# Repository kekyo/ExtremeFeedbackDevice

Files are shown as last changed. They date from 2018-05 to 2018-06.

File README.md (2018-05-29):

# Extreme feedback device (XFD) on ESP8266

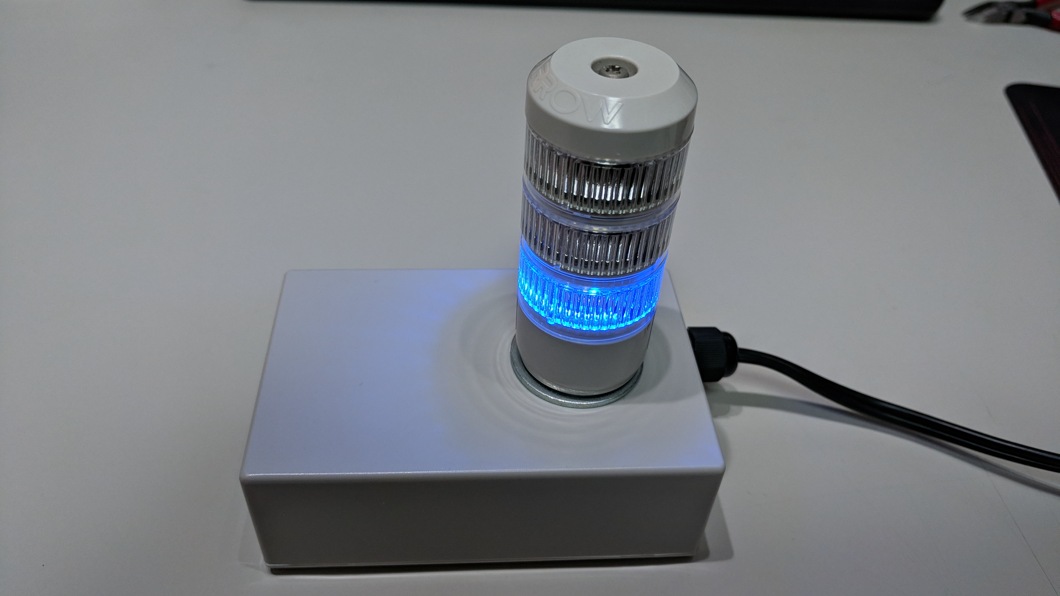
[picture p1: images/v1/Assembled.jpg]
Assembled unit (version 1)


* Still under construction...

## What's this?

* It's extreme feedback device (called XFD useful agile software development) running on ESP8266 (aka ESP-WROOM-02).
* I made custom schematic and artwork.
  * Use EAGLE 8
* I wrote sequencer code by C++ on ESP8266-Arduino IDE. (WIP)

## Features

* We can use signal device with 4 ports.
* For example, port 1, 2, 3 assign signal light's "Green", "Yellow" and "Red" leds. Port 4 assign buzzer.
* Signal device has to have one kind of commonly regulated voltage. I use +24V-0V based signal light.
  * Final output switcher is open-collectored transister using TOSHIBA "TD62064." https://toshiba.semicon-storage.com/info/docget.jsp?did=2229&prodName=TD62064BP1G
  * I use ARROW Electronics "AUSG-24" (In japanese): https://www.proface.co.jp/signaling/product/product_detail.php?unique_id=AUSG

## Schematic and artwork

* I'll order PCB to [Fusion PCB](https://www.seeedstudio.com/fusion_pcb.html).

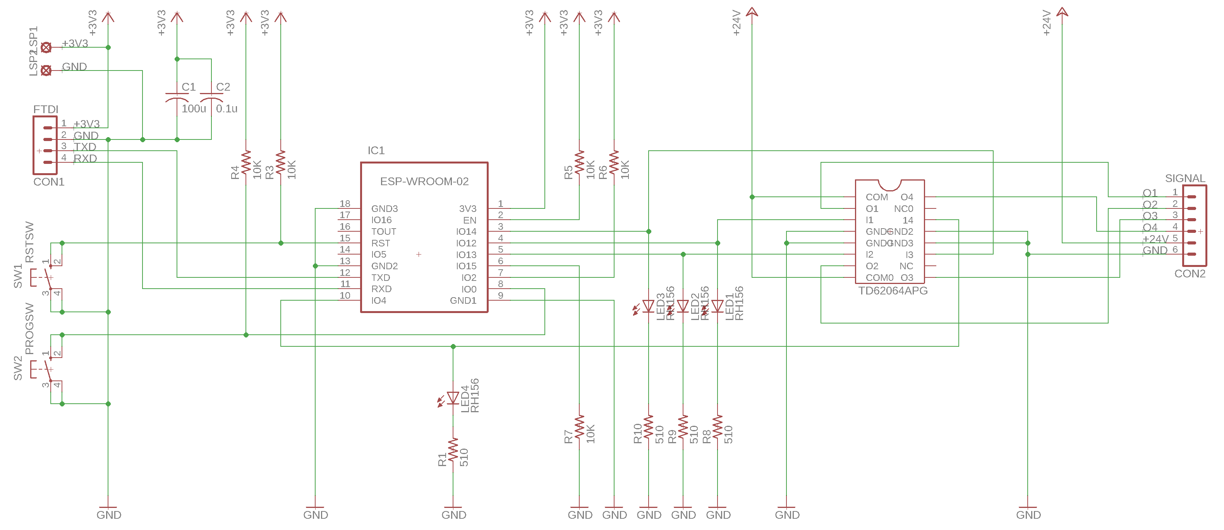
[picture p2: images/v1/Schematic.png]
Schematic


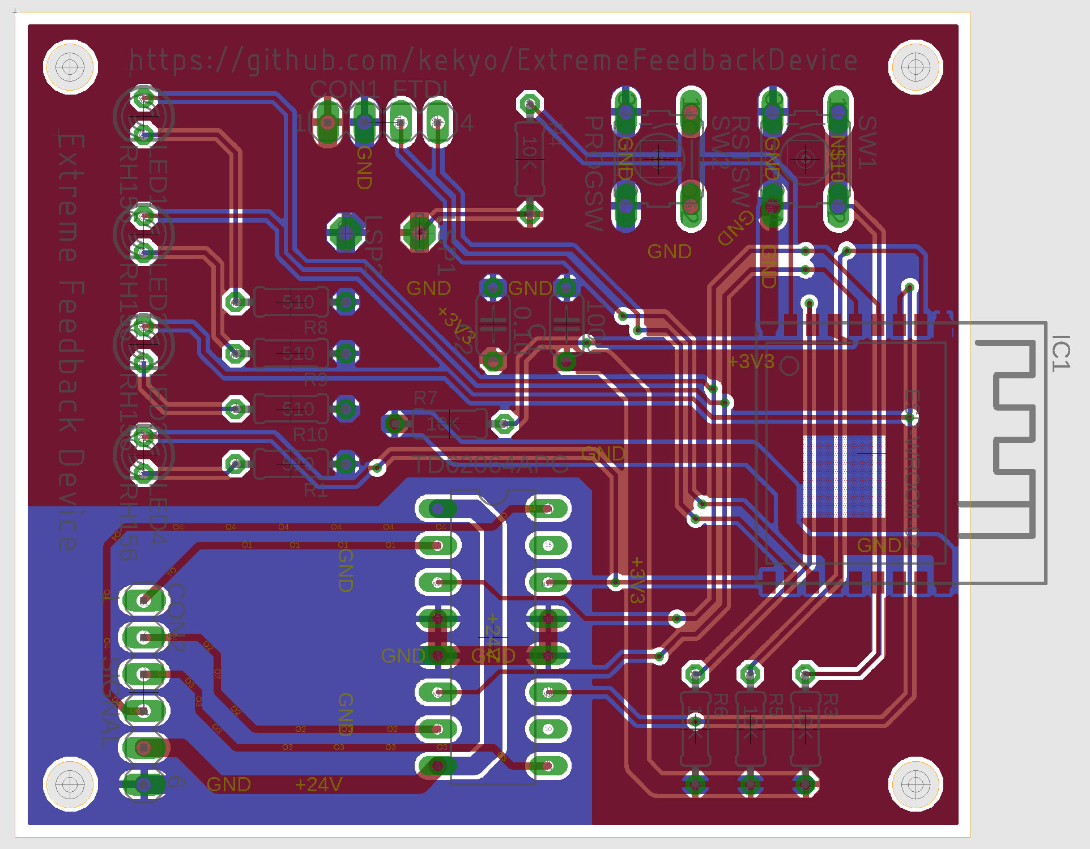
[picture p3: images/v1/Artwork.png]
Artwork


## License

* Under Apache v2

## Background

* At first, I was exciting agile software development weaves. I made XFD device in 2006.
  * It was very standard formal style, using the signal light.
  * I did have no idea how to communicate easy way between PC/Server and devices. So I made with PC's printer parallel port.

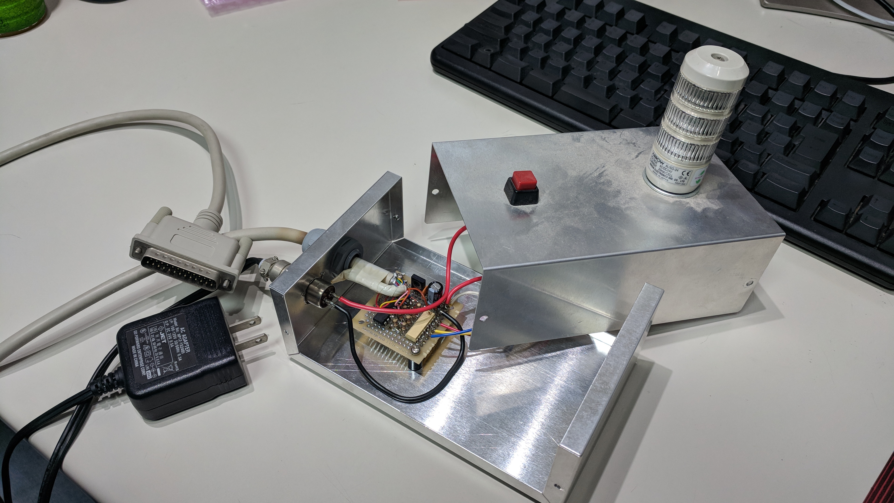
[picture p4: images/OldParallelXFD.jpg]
Old XFD by parallel interface


* Today, we can communicate easier using a lot of procedures, USB/LAN/Wifi/Bluetooth and more. The parallel port obsoleted.
* I'm beginning to redesign for modern-style device communication. The ESP8266 totally better balanced module for IoT platform. I use ESP8266 and redesign XFD for basic boilerplate :)

## History

* first_pcb: Designed output signal with darlington transistor array. It's very simple board, contains only ESP-WROOM-02 and TrA.

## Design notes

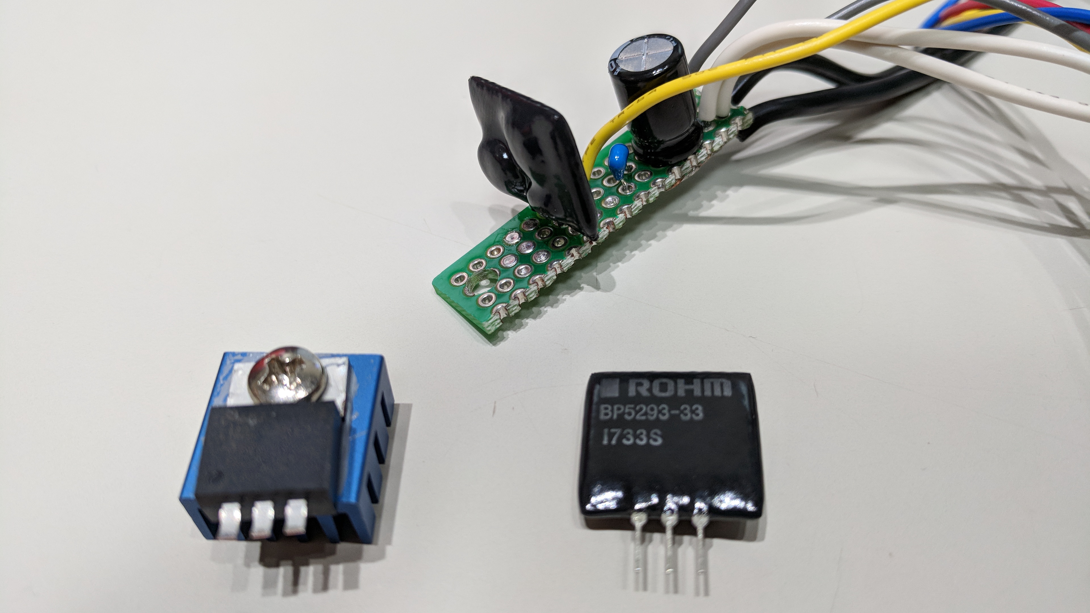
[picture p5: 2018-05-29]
images/v1/SwitchingRegulator.jpg

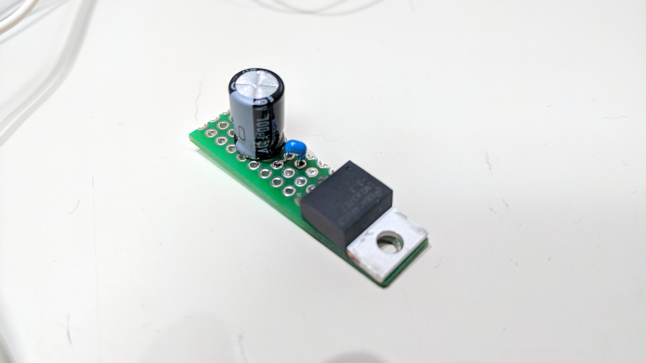
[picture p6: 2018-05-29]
images/v1/PowerBoard.jpg

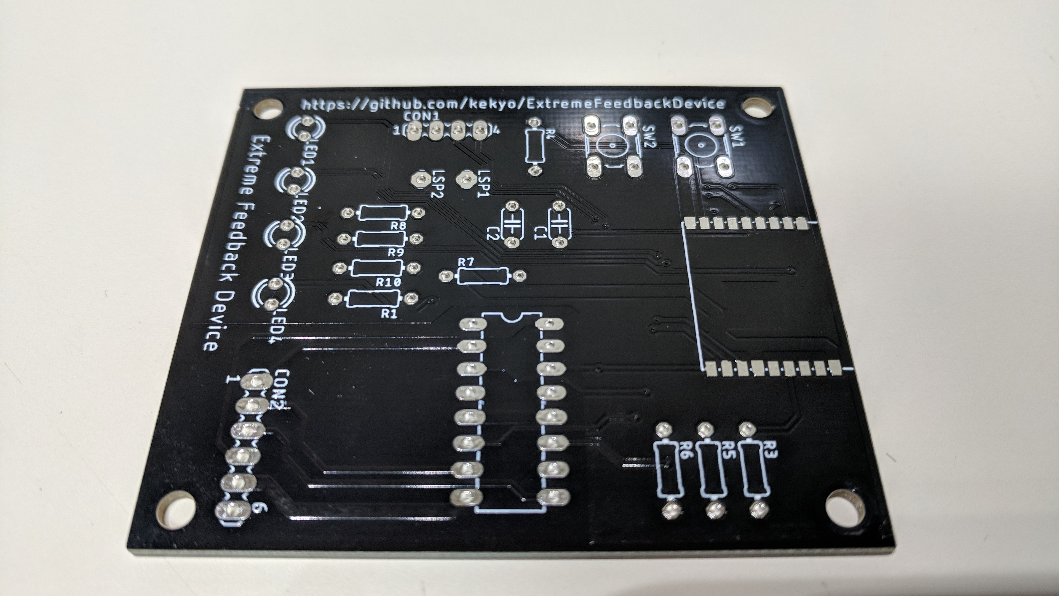
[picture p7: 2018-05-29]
images/v1/Before.jpg

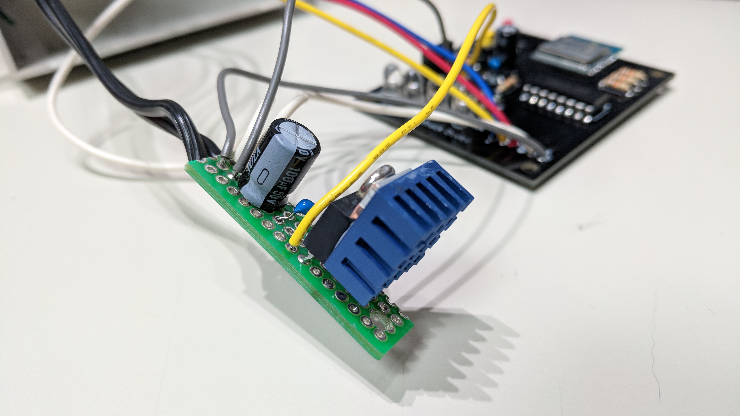
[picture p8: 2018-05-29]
images/v1/TooHotAtRegulator.jpg

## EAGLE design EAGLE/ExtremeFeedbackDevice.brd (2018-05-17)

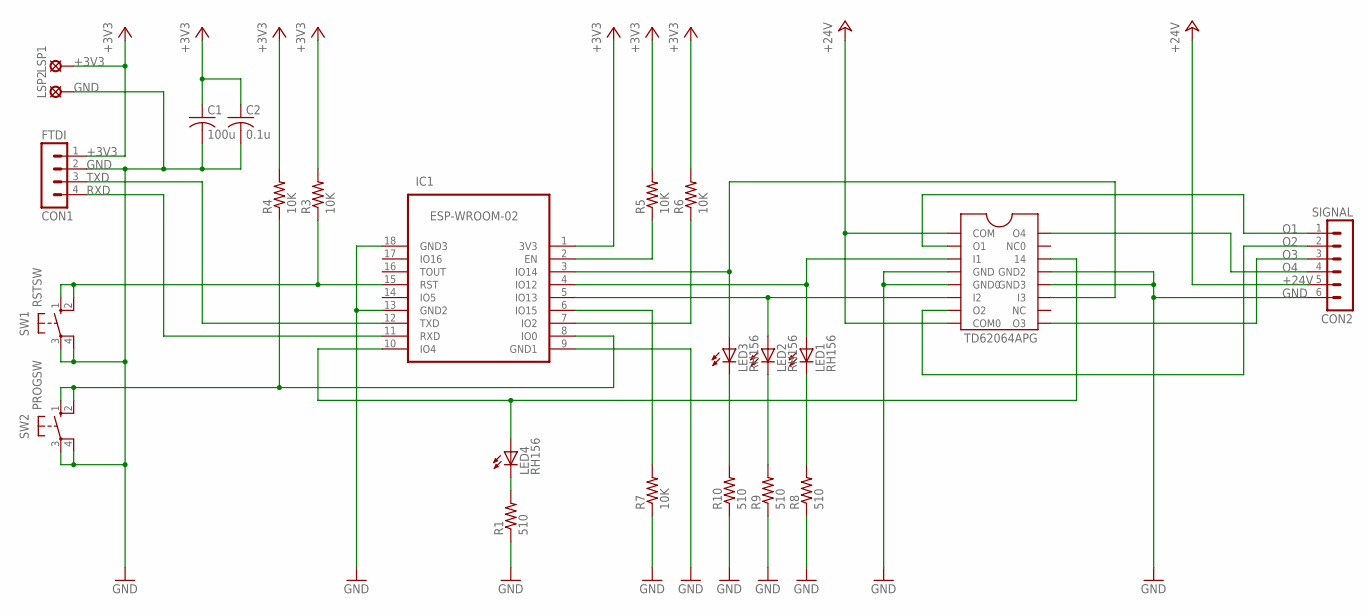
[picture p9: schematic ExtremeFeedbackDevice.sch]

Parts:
C1: 100u; C050-024X044
C2: 0.1u; C050-024X044
CON1: FTDI; MA04-1
CON2: SIGNAL; MA06-1
IC1: ESP-WROOM-02; FRONT-FACE
IC2: IC2; TD62064APG
LED1, LED2, LED3, LED4: RH156; LED3MM
LSP1, LSP2: LSP10
R1, R8, R9, R10: 510; 0204/7
R3, R4, R5, R6, R7: 10K; 0204/7
SW1: RSTSW; B3F-10XX
SW2: PROGSW; B3F-10XX

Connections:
+3V3: C1.1, C2.1, CON1.1, IC1.1 (3V3), LSP1.MP, R3.2, R4.2, R5.2, R6.2
+24V: CON2.5, IC2.1 (COM), IC2.8 (COM0)
GND: C1.2, C2.2, CON1.2, CON2.6, IC1.9 (GND1), IC1.13 (GND2), IC1.18 (GND3), IC2.4 (GND), IC2.5 (GND0), IC2.12 (GND3), IC2.13 (GND2), LSP2.MP, R1.1, R7.1, R8.1, R9.1, R10.1, SW1.3, SW1.4 (P1), SW2.3, SW2.4 (P1)
unnamed: IC1.8 (IO0), R4.1, SW2.1 (S), SW2.2 (S1)
unnamed: IC1.5 (IO13), IC2.6 (I2), LED2.A
unnamed: LED1.K (C), R8.2
unnamed: LED2.K (C), R9.2
unnamed: IC1.3 (IO14), IC2.11 (I3), LED3.A
unnamed: IC1.4 (IO12), IC2.3 (I1), LED1.A
unnamed: IC1.15 (RST), R3.1, SW1.1 (S), SW1.2 (S1)
unnamed: LED3.K (C), R10.2
unnamed: IC1.2 (EN), R5.1
unnamed: IC1.7 (IO2), R6.1
unnamed: IC1.6 (IO15), R7.2
unnamed: IC1.10 (IO4), IC2.14, LED4.A
unnamed: LED4.K (C), R1.2
O1: CON2.1, IC2.2 (O1)
O2: CON2.2, IC2.7 (O2)
O3: CON2.3, IC2.9 (O3)
O4: CON2.4, IC2.16 (O4)
RXD: CON1.4, IC1.11 (RXD)
TXD: CON1.3, IC1.12 (TXD)

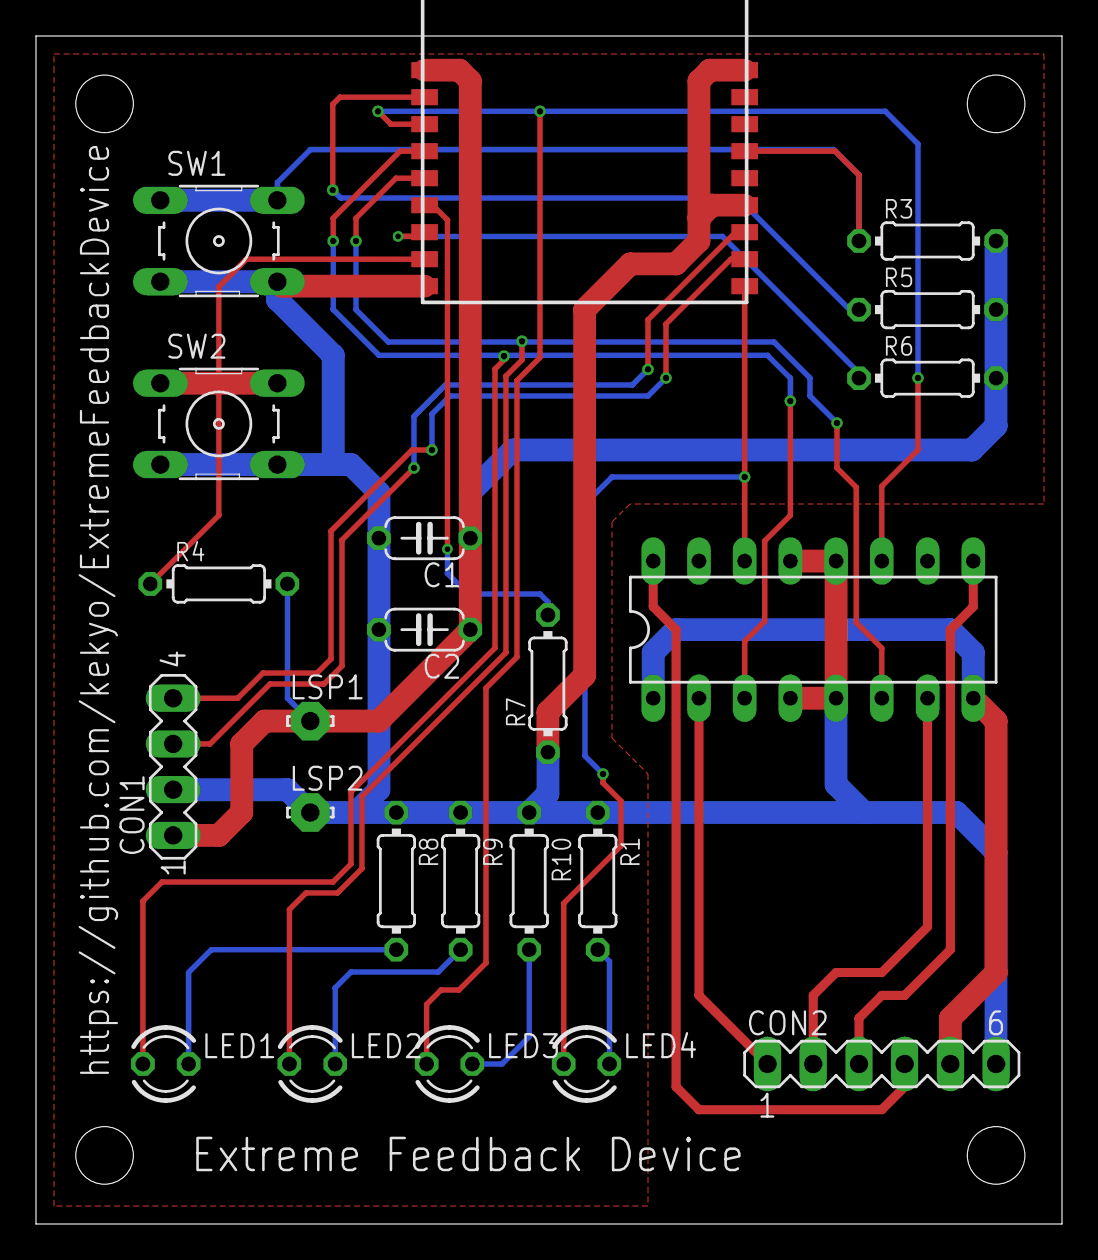
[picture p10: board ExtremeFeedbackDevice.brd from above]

Board: 2 copper layers, 57.0 x 66.0 mm, 23 parts (0 on the bottom side), 22 nets.

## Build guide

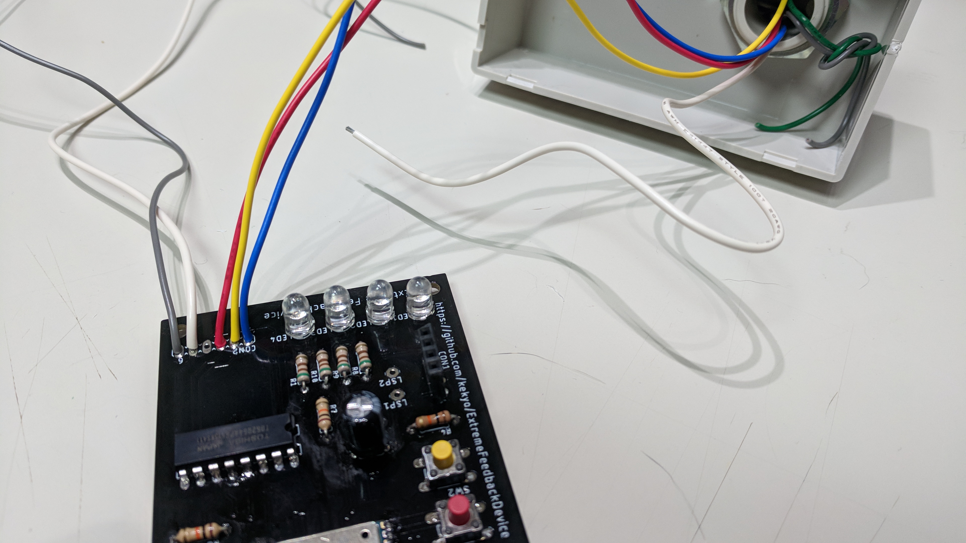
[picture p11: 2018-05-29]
images/v1/AssembleUnit3.jpg

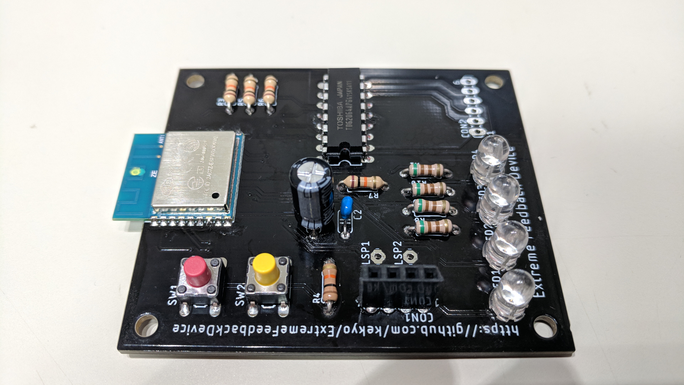
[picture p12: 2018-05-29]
images/v1/Soldered1.jpg

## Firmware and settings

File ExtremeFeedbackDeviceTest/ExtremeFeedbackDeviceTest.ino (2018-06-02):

#include <Wire.h>

#define OUT1 12   // ESP8266 (ESP-WROOM-02) IO12
#define OUT2 13   // ESP8266 (ESP-WROOM-02) IO13
#define OUT3 14   // ESP8266 (ESP-WROOM-02) IO14
#define OUT4 4    // ESP8266 (ESP-WROOM-02) IO4

void setup()
{
    Serial.begin(115200);

    Wire.begin();

    delay(500);

    digitalWrite(OUT1, LOW);
    digitalWrite(OUT2, LOW);
    digitalWrite(OUT3, LOW);
    digitalWrite(OUT4, LOW);

    delay(100);

    pinMode(OUT1, OUTPUT);
    pinMode(OUT2, OUTPUT);
    pinMode(OUT3, OUTPUT);
    pinMode(OUT4, OUTPUT);

    Serial.println("    ");
    Serial.println("Ready");

    delay(200);
}

static const uint8_t pins[4] = { OUT1, OUT2, OUT3, OUT4 };

void loop()
{
    for (auto i = 0; i < 4; i++)
    {
        digitalWrite(pins[i], HIGH);

        delay(500);

        digitalWrite(OUT1, LOW);
        digitalWrite(OUT2, LOW);
        digitalWrite(OUT3, LOW);
        digitalWrite(OUT4, LOW);
    }
}

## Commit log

2018-05-01 Initial commit (WIP)
    [ExtremeFeedbackDevice.brd, ExtremeFeedbackDevice.sch]
2018-05-02 Finished first pcb work.
    [ExtremeFeedbackDevice.GBL, ExtremeFeedbackDevice.GBO, ExtremeFeedbackDevice.GBP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]
2018-05-17 Fixed shifted line (Invalid in DRC)
    [ExtremeFeedbackDevice.brd]
